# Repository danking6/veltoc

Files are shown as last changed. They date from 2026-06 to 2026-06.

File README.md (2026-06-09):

# Veltoc
Veltoc Model 01 is a ESP32 powered, retro-inspired environmental monitor with an E-Ink display. It can monitor temperature, humidity and air pressure. Connect to wifi to also display the current time.

Veltoc-model-01 copy





# Hardware Used

- Xiao ESP32 C6
- <a href="https://www.seeedstudio.com/ePaper-breakout-Board-for-XIAO-V2-p-6374.html">ePaper Driver Board for Seeed Studio XIAO</a>
- <a href="https://www.seeedstudio.com/2-9-Monochrome-ePaper-Display-with-296x128-Pixels-p-5782.html">2.9" Monochrome eInk / ePaper Display</a>
- <a href="https://www.amazon.com/dp/B08728K3YB">Rotary Encoder</a>
- 3mm 3.7v LED
- BME 280 Temperature/Humidity/Pressure sensor
- 2x 100kOhm resistors (for battery level reading)
- <a href="https://www.amazon.com/dp/B095W4HS75">EEMB LiPo Battery 3.7V 1400mAh 112945 Rechargeable Battery</a>
- <a href="https://www.amazon.com/dp/B0D1MW6YPL">USB C Pigtail Cable Extension, Female</a>
- <a href="https://www.amazon.com/dp/B09WCQKSW1">USB C Connector - 24 Pins Male Plug Socket</a>

# Wiring For Xiao ESP32 C6
These are all configurable in the config.h file if using a different ESP32 or pins.

BME280 Sensor

SCL -> D5
SDA -> D4

LED -> D6

Rotary Encoder

Button -> GPIO6 (MTCK pin on bottom) (wake)
Rotation -> D7, D9

Battery voltage sensor

A5 (MTDI pin on bottom)

Note: The battery was soldered directly to the underside battery +/- pins on the Xiao ESP32, as when using the JST connector on the epaper driver board, the battery wouldn't charge.

Create a short USB-C cable (male to female) to connect the ESP32 USB-C port to the back of the case. Solder the USB-C Pigtail Cable Extension (female) wires to the (male) USB-C Connector. Optionally use heat-shrink wrap to cover the solder joints on the male end.

# Software Setup

Arduino Studio was used. Please download the necessary libraries. If using wifi (needed for accurate time), add wifi credentials in voltoc-model-01.ino. Adjust other pins as needed in config.h

# Usage

Press the knob in to wake the device (if sleeping). Rotate the knob to switch between views. For all views except settings, the device will remain on the current view and wake periodically to update. 

When on the settings view, press the knob in to enter settings. Rotate the knob to select a setting to edit, press the knob in to begin editing the selected setting. The device will automatically return to the temperature view after being idle for 30 seconds when in settings view.

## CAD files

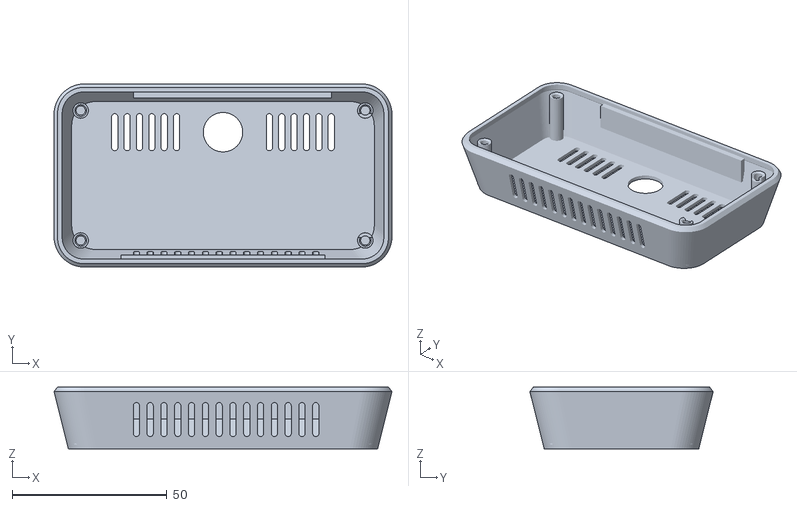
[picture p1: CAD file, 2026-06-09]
3d-models/case-back.stl
109.3 x 59.3 x 20.0

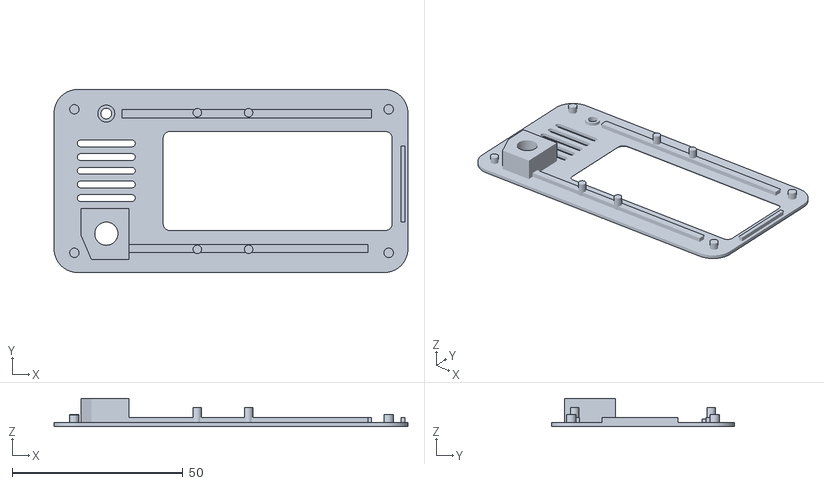
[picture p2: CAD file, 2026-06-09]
3d-models/case-front.stl
103.6 x 53.6 x 8.20

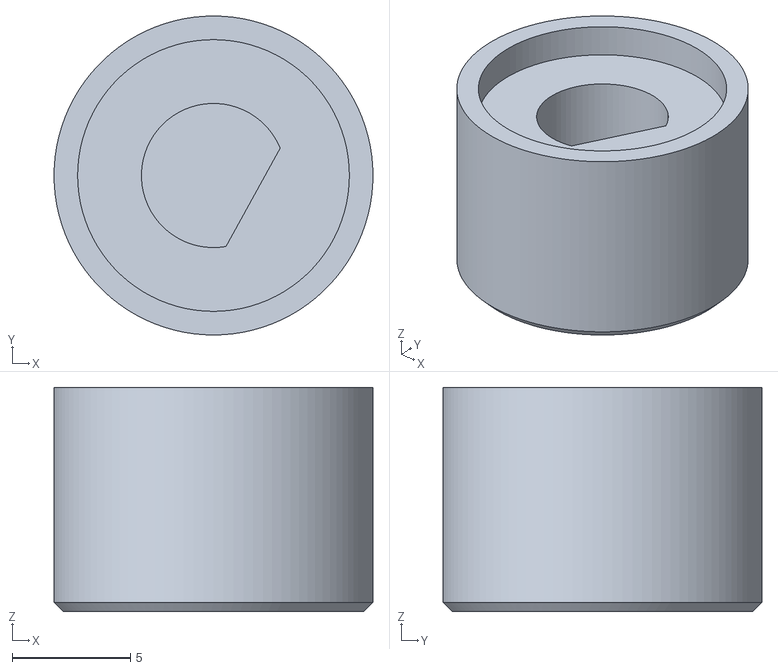
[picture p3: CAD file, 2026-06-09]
3d-models/encoder-knob.stl
13.5 x 13.5 x 9.50

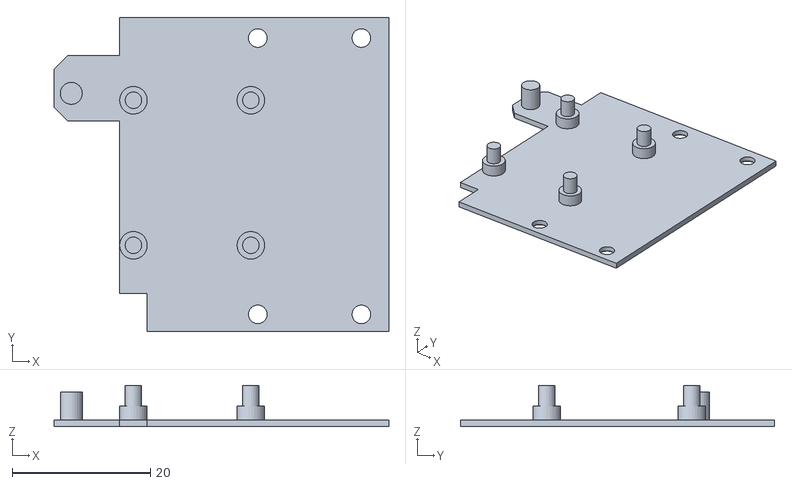
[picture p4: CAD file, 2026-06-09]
3d-models/insert-tray.stl
48.5 x 45.5 x 6.00

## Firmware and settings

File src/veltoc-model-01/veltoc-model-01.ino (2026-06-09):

// Local project files
#include "config.h"
#include "settings.h"
#include "menu.h"
#include "sensors.h"
#include "epaper.h"

// Other config files and packages
#include <ESP32RotaryEncoder.h> // https://github.com/MaffooClock/ESP32RotaryEncoder/tree/main
#include "esp_sleep.h"
#include "esp_sntp.h"
#include "driver/rtc_io.h"
#include <WiFi.h>
#include <time.h>


RotaryEncoder rotaryEncoder( ROT_ENC_A, ROT_ENC_B );

// Vars for button press detection
bool lastReading = HIGH;
bool buttonState = HIGH;
unsigned long lastDebounceTime = 0;
unsigned long debounceDelay = 50;   // ms
unsigned long pressStartTime = 0;
long lastEncoderValue = 0;

unsigned long lastActivityTime = 0;

bool debug = 1;

int wakeTimer = 300; // Seconds to sleep for until next wake
int sleepTimeout = 30; // Seconds before entering sleep. Can change depeneding on the selected view


RTC_DATA_ATTR uint32_t bootCount = 0;
RTC_DATA_ATTR uint16_t timeSyncFailures = 100;

const char* WIFI_SSID = "";
const char* WIFI_PASSWORD = "";
const char* ntpServer = "pool.ntp.org";
const char* timezoneString = "EST5EDT,M3.2.0,M11.1.0"; // POSIX timezone rule



/**
 * ESP32 setup function
 *
 */
void setup()
{
  pinMode(ACTIVITY_LED_PIN, OUTPUT);
  analogWrite(ACTIVITY_LED_PIN, settings.activityLed ? 25 : 0);
  
  Serial.begin(115200);
  
  // Start activity timer
  lastActivityTime = millis();

  bootCount++;

 
  pinMode(ROT_ENC_BTN, INPUT_PULLUP);
  pinMode(ROT_ENC_A, INPUT_PULLUP);
  pinMode(ROT_ENC_B, INPUT_PULLUP);

  rotaryEncoder.setEncoderType( EncoderType::FLOATING ); 
  rotaryEncoder.setBoundaries( -1000, 1000, false );
  rotaryEncoder.onTurned( &knobCallback );
  rotaryEncoder.begin();
  
  // reset states
  appState.inEditMode = false;
  appState.inSettingsMenu = false;

  //ESP_SLEEP_WAKEUP_TIMER or ESP_SLEEP_WAKEUP_UNDEFINED
  esp_sleep_wakeup_cause_t wakeReason = esp_sleep_get_wakeup_cause();
  bool manualWake = false;
  if (wakeReason == ESP_SLEEP_WAKEUP_UNDEFINED || wakeReason == ESP_SLEEP_WAKEUP_EXT1) {
    manualWake = true;
    sleepTimeout = 30;
    Serial.println("Manual wake");
  }
  else {
    sleepTimeout = 0;
    Serial.println("Auto/timed wake");
  }

  
  // Sync time over wifi every 60 startups
  if (bootCount == 1 || (bootCount % 60 == 0)) {
    connectWiFi();
    if (WiFi.status() == WL_CONNECTED){
      syncTime();
      disconnectWiFi();
    }
  } 
  setenv("TZ", timezoneString, 1);
  tzset();

  // read sensors
  readBME280Sensor();
  readVoltageSensor();
  
  initEpaper();
  

  // Battery low/dead notification
  if (battPercent <= 5) { 
    appState.currentView = VIEW_FULLSCREEN_NOTIF;
    appState.fullscreenNotif = BATTERY;
    appState.viewChanged = true;
  }

  if (bootCount == 1 || (bootCount % 30 == 0)) {
    appState.fullRedrawNeeded = true;
    appState.viewChanged = true;
  }
  else {
    appState.partialViewChanged = true;
  }
} //End setup()


/**
 * Main loop 
 *
 */
void loop() 
{
  checkButton();

  //digitalWrite(ACTIVITY_LED_PIN, settings.activityLed ? HIGH : LOW);
  //analogWrite(ACTIVITY_LED_PIN, settings.activityLed ? 25 : 0);

  // Whole screen changed, ie. rotary encoder knob turned
  if (appState.viewChanged) {
    drawCurrentView();
    appState.viewChanged = false;
  }
 
  // Partial screen changed
  if (appState.partialViewChanged) {
    drawCurrentPartial();
    appState.partialViewChanged = false;
  }

  // Check inactivity timeout and sleep
  if ((millis() - lastActivityTime) > (sleepTimeout * 1000)) {
    goToSleep(0);
  }
}


/**
 * Rotary encoder knob rotated
 *
 * 
 */
void knobCallback( long value )
{
  //Serial.printf( "Raw value: %i\n", value );
  lastActivityTime = millis();
  Serial.printf( "last activity time: %i\n", lastActivityTime );
  if(lastEncoderValue < value) {
    if (appState.currentView == VIEW_SETTINGS && appState.inSettingsMenu) {
      encoderCW();
    } else {
      nextView();
    }
  }
  else {
    if (appState.currentView == VIEW_SETTINGS && appState.inSettingsMenu) {
      encoderCCW();
    } else {
      previousView();
    }
  }

  appState.viewChanged = true;
  lastEncoderValue = value;
}

/**
 * Next view
 * 
 */
void nextView() 
{
  appState.currentView = (ScreenView)((appState.currentView + 1) % (VIEW_COUNT-1));
}

/**
 * Previous view
 * 
 */
void previousView() 
{
  int view = appState.currentView - 1;

  if (view < 0) {
    view = VIEW_COUNT - 2;
  }

  appState.currentView = (ScreenView)view;
}

/**
* Encoder rotation in settings menu
*/
void encoderCW() {

  if (!appState.inEditMode) {

    appState.selectedMenuIndex++;

    if (appState.selectedMenuIndex >= settingsMenuCount) {
      appState.selectedMenuIndex = 0;
    }

  } else {

    // modify setting value
    (*editingItem->value)++;
    
    if(*editingItem->value >= editingItem->optionCount)
      *editingItem->value = 0;
    
    //Serial.println("editnig item: " + String(*editingItem->value) + ", option count:" + String(editingItem->optionCount));
  }
}

/**
* Encoder rotation in settings menu
*/
void encoderCCW() {

  if (!appState.inEditMode) {

    appState.selectedMenuIndex--;

    if (appState.selectedMenuIndex < 0) {
      appState.selectedMenuIndex =
        settingsMenuCount - 1;
    }

  } else {

    // modify setting value
    (*editingItem->value)--;
    //Serial.println("editnig item: " + String(*editingItem->value) + ", option count:" + String(editingItem->optionCount));

  if(*editingItem->value < 0)
    *editingItem->value = editingItem->optionCount - 1;

  }
}


/**
 * Rotary encoder button pushed
 *
 * 
 */
void buttonCallback( unsigned long duration )
{
   Serial.printf( "Button pressed for %u ms\n", duration );
   lastActivityTime = millis();

  if (appState.currentView == VIEW_SETTINGS && ! appState.inSettingsMenu) {
    appState.inSettingsMenu = true;
    appState.viewChanged = true;
    return;
  }

  if (appState.currentView == VIEW_SETTINGS) {
    if (!appState.inEditMode) {
      // Enter edit mode
      appState.inEditMode = true;
      
      editingItem = &settingsMenu[appState.selectedMenuIndex];
    }
    else {
      appState.inEditMode = false;
    }
  }

  appState.viewChanged = true;
}

/**
 * Custom rotary encoder button check. (The ESP32RotaryEncoder.h library was
 * missing button presses)
 */
void checkButton() 
{
  bool reading = digitalRead(ROT_ENC_BTN);

  // Reset debounce timer if state changed
  if (reading != lastReading) {
    lastDebounceTime = millis();
  }

  // If stable longer than debounce delay
  if ((millis() - lastDebounceTime) > debounceDelay) {

    if (reading != buttonState) {
      buttonState = reading;

      // Button pressed
      if (buttonState == LOW) {
        pressStartTime = millis();
      }

      // Button released
      if (buttonState == HIGH) {
        buttonCallback(millis() - pressStartTime);
      }
    }
  }

  lastReading = reading;
}


/**
 * Deep sleep after delay seconds
 * @param int delay seconds
 *
 */
void goToSleep(int timeout)
{
  timeout = timeout * 1000;
  if (timeout > 0) {
    Serial.println("Staying awake for a bit...");
    // Stay awake for x seconds
    delay(timeout);
  }

  // Time view, wake every minute, on :00
  if (appState.currentView == VIEW_TIME) {
    time_t epoch = time(nullptr);
    wakeTimer = 60 - (epoch % 60);
    if (wakeTimer > 65) { wakeTimer = 60; }
  }
  // Ssettings view, reset to temperature view
  if (appState.currentView == VIEW_SETTINGS) {
    appState.currentView = VIEW_TEMPERATURE;
    drawCurrentView();
  }

  Serial.println("Entering deep sleep now.");

  esp_sleep_enable_timer_wakeup(wakeTimer * 1000000); 

  // Wake when ANY selected pin goes LOW. (ESP32 C6 doesn't have Ext0 functionality)
  esp_sleep_enable_ext1_wakeup(BUTTON_PIN_BITMASK, ESP_EXT1_WAKEUP_ANY_LOW);
  rtc_gpio_isolate(ROT_ENC_BTN);

  //delay(100); // allow serial to flush
  esp_deep_sleep_start();
}



void connectWiFi()
{
  Serial.print("Connecting to Wifi ");

  WiFi.begin(WIFI_SSID, WIFI_PASSWORD);

  uint8_t retries = 0;
  while (WiFi.status() != WL_CONNECTED && retries < 20) {
    delay(500);
    Serial.print(".");
  }

  if (retries <= 20) {
    Serial.println(" Wifi connected");
  } else {
    Serial.println(" Unable to connect to Wifi");
  }
}


void disconnectWiFi()
{
  WiFi.disconnect(true);
  WiFi.mode(WIFI_OFF);
}


void syncTime()
{
  Serial.print("Synchronizing time from server. ");
  time_t before;
  time(&before);
  Serial.print("Before sync: ");
  Serial.print(before);

  configTime(0, 0, ntpServer);

  //delay(4000);

  uint8_t retries = 0;
  while (sntp_get_sync_status() != SNTP_SYNC_STATUS_COMPLETED && retries < 20) {
    delay(500);
    Serial.print(".");
    retries++;
  }

  if (retries == 20) {
    Serial.println("Time sync failed!");
    timeSyncFailures++;
  } else {
    timeSyncFailures = 0;
    time_t after;
    time(&after);
    Serial.print("After sync: ");
    Serial.println(after);
  }
}

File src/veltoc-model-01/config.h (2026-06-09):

// Pins, constants, settings
#pragma once



// Rotary encoder
#define ROT_ENC_BTN GPIO_NUM_6
#define ROT_ENC_B GPIO_NUM_20
#define ROT_ENC_A GPIO_NUM_17

#define BUTTON_PIN_BITMASK (1ULL << GPIO_NUM_6) // GPIO bitmask for ext1 wakeup

// Pins for epaper
#define EPD_CS   D1
#define EPD_DC   D3
#define EPD_RST  D0
#define EPD_BUSY D2
// Pins need to be connected as follows for epaper
//#define EPD_SCK  D8 //CLK
//#define EPD_MOSI D10 //DIN

// Battery
#define BATTERY_ADC_PIN 5

// LED
#define ACTIVITY_LED_PIN D6

//#define TIME_TO_SLEEP 30      //Seconds of inactivity before sleep

// Adjust as needed for temp/hum accuracy
#define TEMPERATURE_OFFSET 0
#define HUMIDITY_OFFSET 0

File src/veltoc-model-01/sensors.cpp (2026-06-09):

#include "config.h"
#include "sensors.h"

float temperatureSensor = 0.0;
float humiditySensor = 0.0;
float pressureSensor = 0.0;

float battPercent = 0.0;
float battVoltage = 0.0;

Adafruit_BME280 bme; // I2C

/**
 * Read from sensor BME280
 *
 */
void readBME280Sensor()
{
   if (!bme.begin(0x76)) {
    Serial.println(F("BME280 not found"));
    //while (1);
    return;
  }

  delay(200); 
  
  temperatureSensor = bme.readTemperature() + TEMPERATURE_OFFSET;
  humiditySensor = bme.readHumidity() + HUMIDITY_OFFSET;
  pressureSensor = bme.readPressure() / 100.0F;
}

/**
 *
 *
 */
void readVoltageSensor()
{
  Serial.print("Measuring battery");
  // Battery voltage reading
  pinMode(BATTERY_ADC_PIN, INPUT); 
  delay(50);
  
  uint32_t Vbatt = 0;
  for(int i = 0; i < 16; i++) {
    Vbatt = Vbatt + analogReadMilliVolts(BATTERY_ADC_PIN); // ADC with correction   
  }
  
  battVoltage = 2 * Vbatt / 16 / 1000.0; 
  float voltage = battVoltage;
  
  if (voltage < 0) voltage = 0; // Prevent negative voltage

  if (voltage < 2.75) {
    battVoltage = 0.0;
    battPercent = 0.0;
    Serial.printf(", voltage: %.2fV (too low or not connected)\n", voltage);
  } else {
    // Calculate battery percentage from emaVoltage
    // Lookup table algorithm: precise mapping of lithium battery discharge curve
    float localBatteryPercentage;
    if (battVoltage >= 4.15f) localBatteryPercentage = 100.0f;
    else if (battVoltage >= 4.0f) localBatteryPercentage = 96.3f + (battVoltage - 4.0f) * 24.5f;
    else if (battVoltage >= 3.7f) localBatteryPercentage = 53.3f + (battVoltage - 3.7f) * 143.5f;
    else if (battVoltage >= 3.5f) localBatteryPercentage = 6.1f + (battVoltage - 3.5f) * 235.7f;
    else if (battVoltage >= 3.0f) localBatteryPercentage = (battVoltage - 3.0f) * 12.3f;
    else localBatteryPercentage = 0.0f;

    // Clamp to 0-100 range
    battPercent = constrain(localBatteryPercentage, 0.0f, 100.0f);
    
    Serial.printf(", voltage: %.2fv (%.2f%%)\n", battVoltage, battPercent);
  }
}
